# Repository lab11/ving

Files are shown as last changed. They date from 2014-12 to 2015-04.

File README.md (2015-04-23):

Rumblecation
=======

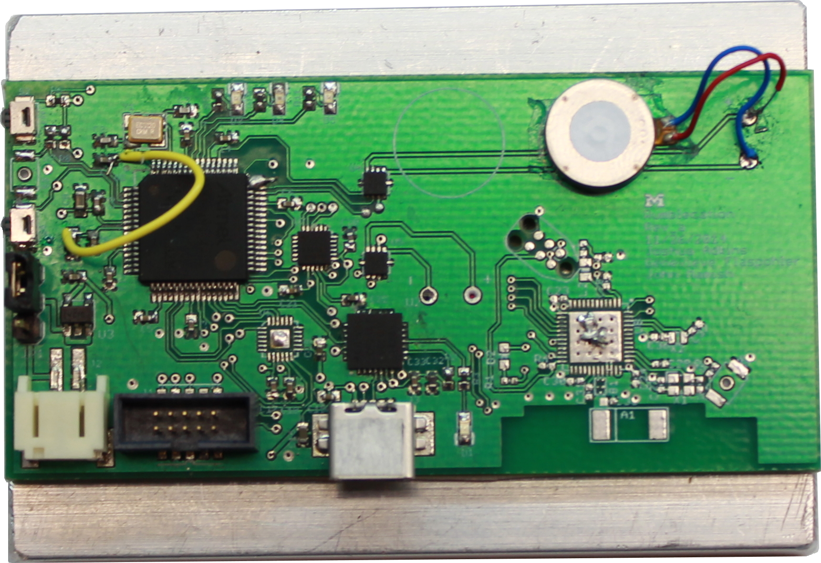
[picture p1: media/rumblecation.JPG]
Vibratory Communication Device


Mobile phones have vibratory motors which can transmit vibration, and 
accelerometers, which can sense vibration. Rumblecation takes advantage
of this hardware to communicate over vibration. Vibratory communication
would limit the communication domain to two or more physically coupled
devices, and this could be used to pair a specific subset of devices
sharing a surface such as table. 

Custom hardware was developed to closely emulate the hardware found in
common smartphones. A simple protocol was then designed for vibratory
communication and firmware was developed for our hardware to implement
this protocol.

Current work is focused on improving data rate and reliability, which
should be achievable by improving the algorithms that are processing 
accelerometer data.

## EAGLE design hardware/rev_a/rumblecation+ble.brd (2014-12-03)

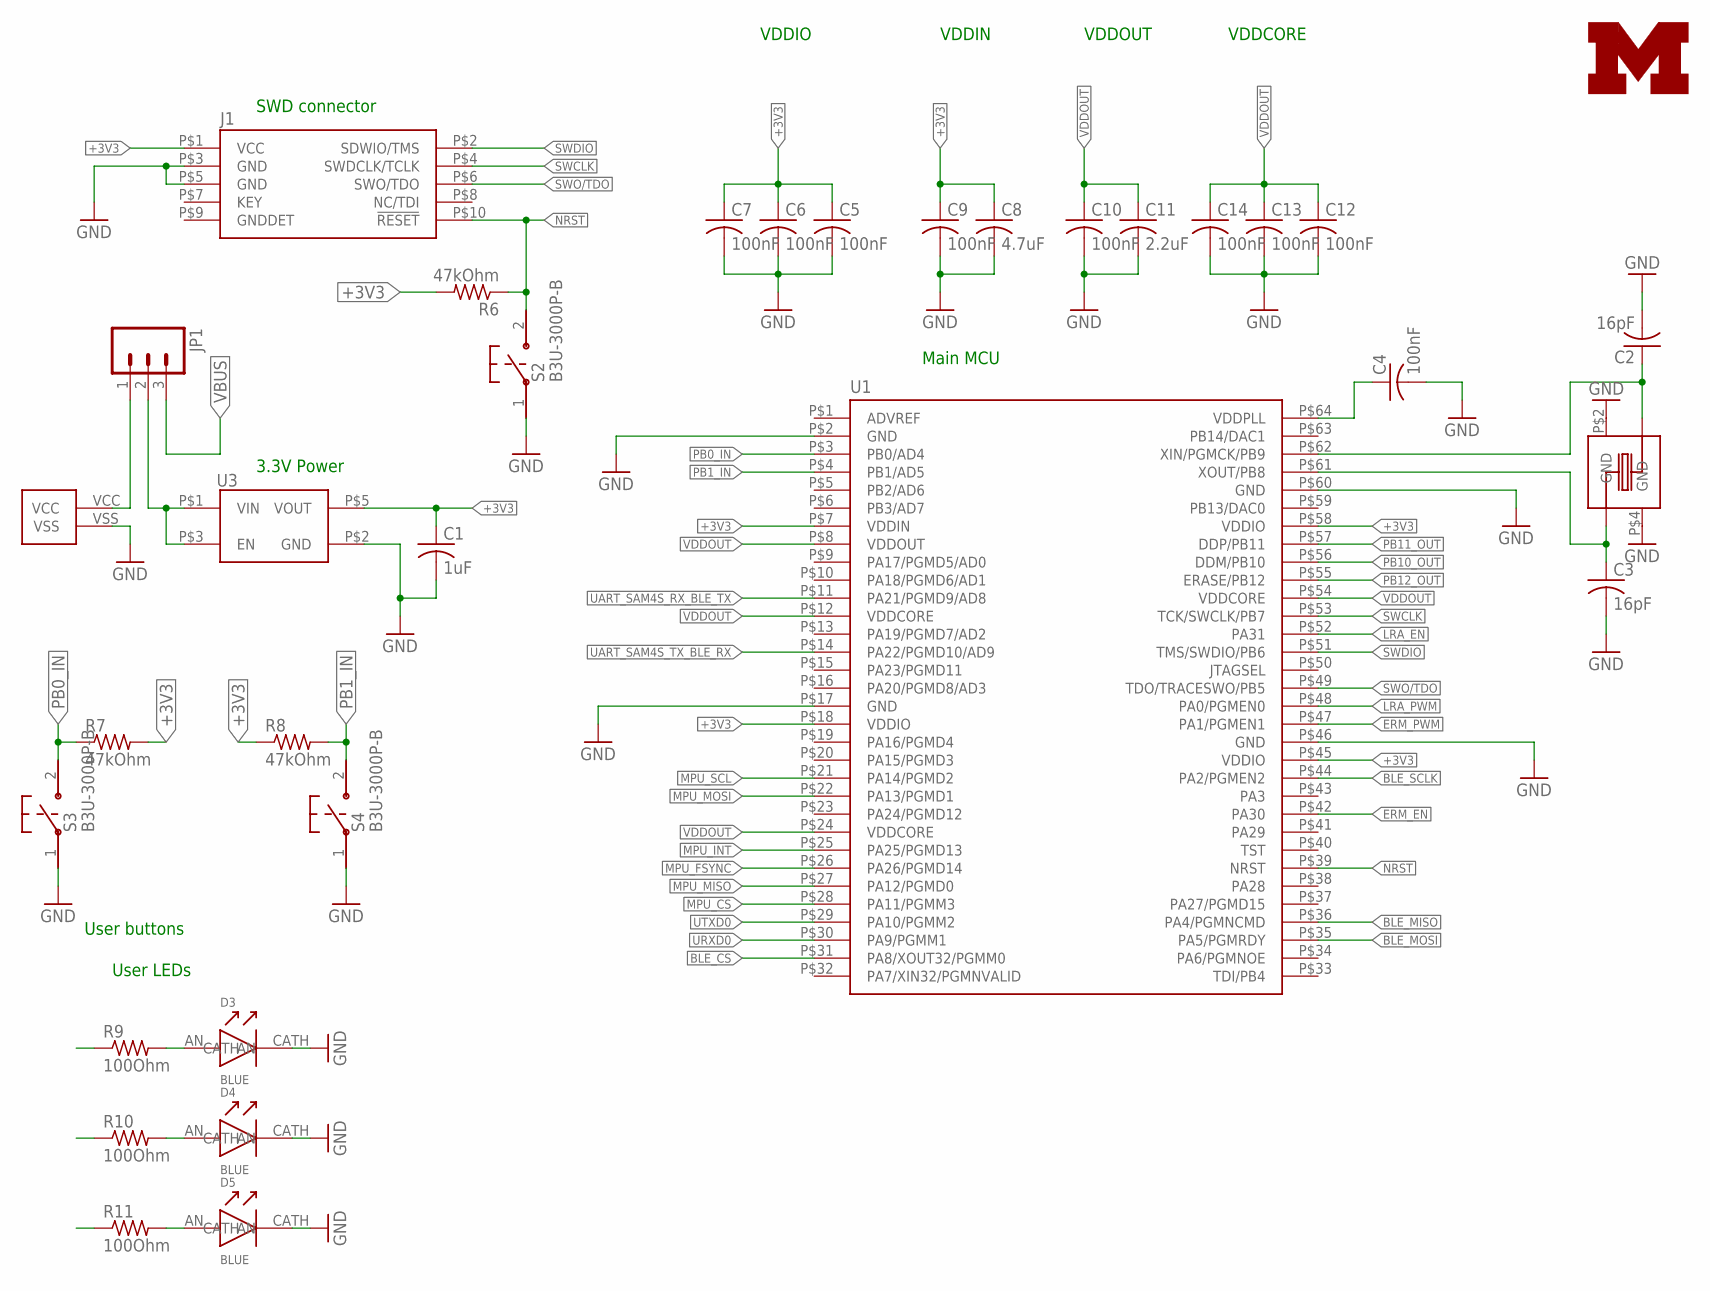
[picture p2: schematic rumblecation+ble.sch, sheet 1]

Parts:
C1: 1uF; C0402
C2, C3: 16pF; C0402
C4, C5, C6, C7, C9, C10, C12, C13, C14: 100nF; C0402
C8: 4.7uF; C0603
C11: 2.2uF; C0603
D3, D4, D5: BLUE; D0603
J1: FCI_CORTEX_SWD_CONNECTOR; FCI_10_PIN_SMD_0.5
J2: JST_S2B-PH-SM4-TB_CONNECTOR
JP1: M03PTH; 1X03
LOGO1: UMICH_SOLID_TINY; UMICH_SOLID_50MIL
R6, R7, R8: 47kOhm; R0402
R9, R10, R11: 100Ohm; R0402
S2, S3, S4: B3U-3000P-B
U1: ATSAM4S2BA-AU; ATMEL_10X10_QFP_64
U3: TLV73333PDBVT; TI_SOT-23-5
Y1: ECS_ECS-120-20-33-CKM-TR; ECS_ECX-32

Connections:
+3V3: C1.1, C5.1, C6.1, C7.1, C8.1, C9.1, J1.P$1 (VCC), R6.2, R7.2, R8.1, U1.P$7 (VDDIN), U1.P$18 (VDDIO), U1.P$45 (VDDIO), U1.P$58 (VDDIO), U3.P$5 (VOUT); also elsewhere on the board
BLE_CS: U1.P$31 (PA8/XOUT32/PGMM0); also elsewhere on the board
BLE_MISO: U1.P$36 (PA4/PGMNCMD); also elsewhere on the board
BLE_MOSI: U1.P$35 (PA5/PGMRDY); also elsewhere on the board
BLE_SCLK: U1.P$44 (PA2/PGMEN2); also elsewhere on the board
ERM_EN: U1.P$42 (PA30); also elsewhere on the board
ERM_PWM: U1.P$47 (PA1/PGMEN1); also elsewhere on the board
GND: C1.2, C2.2, C3.2, C4.2, C5.2, C6.2, C7.2, C8.2, C9.2, C10.2, C11.2, C12.2, C13.2, C14.2, D3.CATH, D4.CATH, D5.CATH, J1.P$3 (GND), J1.P$5 (GND), J2.VSS, S2.1, S3.1, S4.1, U1.P$2 (GND), U1.P$17 (GND), U1.P$46 (GND), U1.P$60 (GND), U3.P$2 (GND), Y1.P$2 (GND), Y1.P$4 (GND); also elsewhere on the board
LRA_EN: U1.P$52 (PA31); also elsewhere on the board
LRA_PWM: U1.P$48 (PA0/PGMEN0); also elsewhere on the board
MPU_CS: U1.P$28 (PA11/PGMM3); also elsewhere on the board
MPU_FSYNC: U1.P$26 (PA26/PGMD14); also elsewhere on the board
MPU_INT: U1.P$25 (PA25/PGMD13); also elsewhere on the board
MPU_MISO: U1.P$27 (PA12/PGMD0); also elsewhere on the board
MPU_MOSI: U1.P$22 (PA13/PGMD1); also elsewhere on the board
MPU_SCL: U1.P$21 (PA14/PGMD2); also elsewhere on the board
unnamed: JP1.2, U3.P$1 (VIN), U3.P$3 (EN)
unnamed: C4.1, U1.P$64 (VDDPLL)
unnamed: J2.VCC, JP1.1
unnamed: D3.AN, R9.2
unnamed: D4.AN, R10.2
unnamed: D5.AN, R11.2
NRST: J1.P$10 (!RESET!), R6.1, S2.2, U1.P$39 (NRST)
PB0_IN: R7.1, S3.2, U1.P$3 (PB0/AD4)
PB1_IN: R8.2, S4.2, U1.P$4 (PB1/AD5)
PB10_OUT: R10.1, U1.P$56 (DDM/PB10)
PB11_OUT: R9.1, U1.P$57 (DDP/PB11)
PB12_OUT: R11.1, U1.P$55 (ERASE/PB12)
SWCLK: J1.P$4 (SWDCLK/TCLK), U1.P$53 (TCK/SWCLK/PB7)
SWDIO: J1.P$2 (SDWIO/TMS), U1.P$51 (TMS/SWDIO/PB6)
SWO/TDO: J1.P$6 (SWO/TDO), U1.P$49 (TDO/TRACESWO/PB5)
UART_SAM4S_RX_BLE_TX: U1.P$11 (PA21/PGMD9/AD8); also elsewhere on the board
UART_SAM4S_TX_BLE_RX: U1.P$14 (PA22/PGMD10/AD9); also elsewhere on the board
URXD0: U1.P$30 (PA9/PGMM1); also elsewhere on the board
UTXD0: U1.P$29 (PA10/PGMM2); also elsewhere on the board
VBUS: JP1.3; also elsewhere on the board
VDDOUT: C10.1, C11.1, C12.1, C13.1, C14.1, U1.P$8 (VDDOUT), U1.P$12 (VDDCORE), U1.P$24 (VDDCORE), U1.P$54 (VDDCORE)
XIN: C2.1, U1.P$62 (XIN/PGMCK/PB9), Y1.P$1
XOUT: C3.1, U1.P$61 (XOUT/PB8), Y1.P$3

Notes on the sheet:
VDDIN
VDDOUT
VDDIO
VDDCORE
3.3V Power
SWD connector
Main MCU
User buttons
User LEDs

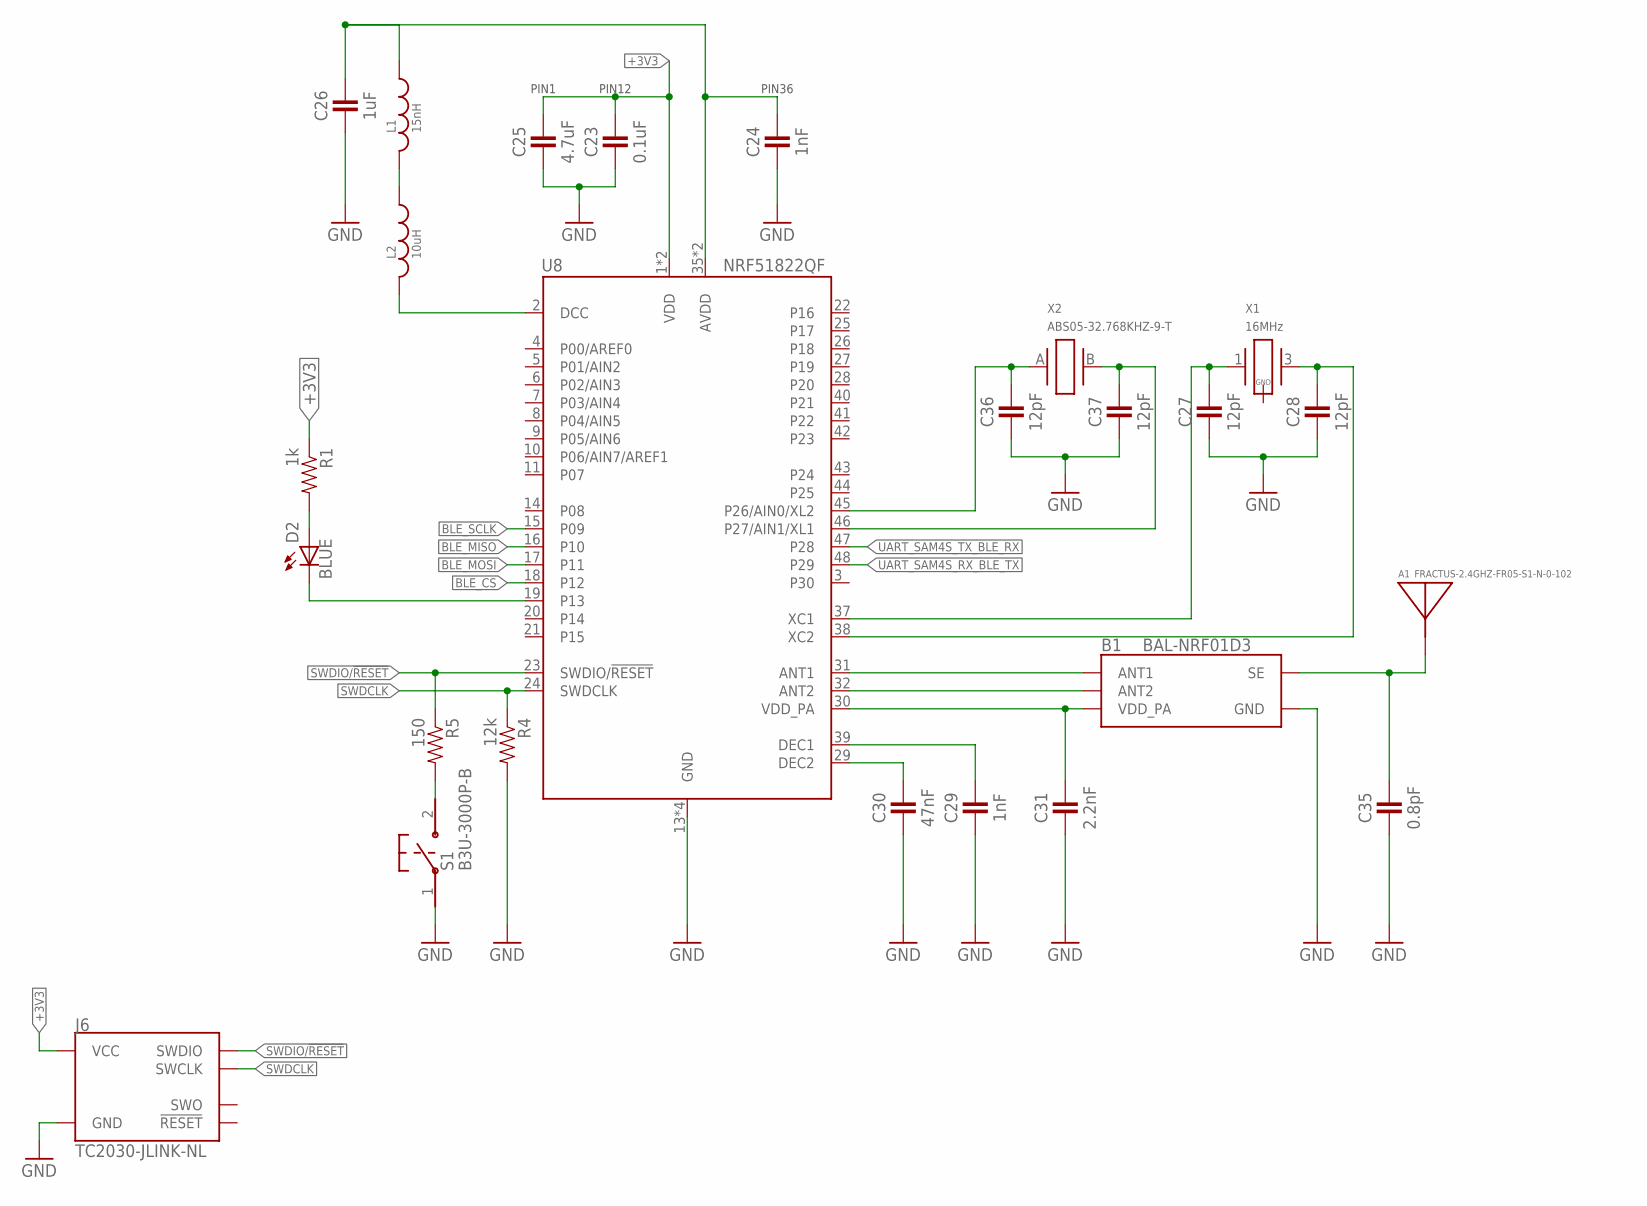
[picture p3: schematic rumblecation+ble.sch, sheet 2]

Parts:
A1: FRACTUS-2.4GHZ-FR05-S1-N-0-102; FRACTUS-ANTENNA-FR05-S1-N-0-102
B1: BAL-NRF01D3
C23: 0.1uF; 0402_CAP; DIGIKEY 445-4952-1-ND
C24, C29: 1nF; 0402_CAP; DIGIKEY 490-1303-1-ND
C25: 4.7uF; 0402_CAP; DIGIKEY 445-5947-1-ND
C26: 1uF; 0402_CAP; DIGIKEY 1276-1513-1-ND
C27, C28, C36, C37: 12pF; 0402_CAP; DIGIKEY 490-6197-1-ND
C30: 47nF; 0402_CAP; DIGIKEY 445-1264-1-ND
C31: 2.2nF; 0402_CAP; DIGIKEY 490-5419-1-ND
C35: 0.8pF; 0402_CAP; DIGIKEY 490-6269-1-ND
D2: BLUE; LED-0603
J6: TC2030-JLINK-NL; TC2030-IDC-NL
L1: 15nH; 0402_CAP; DIGIKEY 587-1521-1-ND
L2: 10uH; 0603_CAP; DIGIKEY 490-4025-1-ND
R1: 1k; 0402_RES; DIGIKEY RHM1.0KCECT-ND
R4: 12k; 0402_RES; DIGIKEY RHM12.0KCDCT-ND
R5: 150; 0402_RES; DIGIKEY RHM150CDCT-ND
S1: B3U-3000P-B
U8: NRF51822QF; QFN-48-6MM
X1: 16MHz; TXC-8Y; DIGIKEY 887-2003-1-ND
X2: ABS05-32.768KHZ-9-T; ABS05

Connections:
+3V3: C23.1, C25.1, J6.1 (VCC), R1.1, U8.1 (VDD), U8.12 (VDD); also elsewhere on the board
A0: C36.1, U8.45 (P26/AIN0/XL2), X2.A (1)
A1: C37.1, U8.46 (P27/AIN1/XL1), X2.B (2)
AVDD: C24.1, C26.1, L1.1, U8.35 (AVDD), U8.36 (AVDD)
BLE_CS: U8.18 (P12); also elsewhere on the board
BLE_MISO: U8.16 (P10); also elsewhere on the board
BLE_MOSI: U8.17 (P11); also elsewhere on the board
BLE_SCLK: U8.15 (P09); also elsewhere on the board
DCC: L2.2, U8.2 (DCC)
GND: B1.GND, C23.2, C24.2, C25.2, C26.2, C27.2, C28.2, C29.2, C30.2, C31.2, C35.2, C36.2, C37.2, J6.5 (GND), R4.2, S1.1, U8.13 (GND), U8.33 (GND), U8.34 (GND), U8.GND; also elsewhere on the board
unnamed: B1.ANT1, U8.31 (ANT1)
unnamed: B1.ANT2, U8.32 (ANT2)
unnamed: A1.1, B1.SE, C35.1
unnamed: L1.2, L2.1
unnamed: D2.C, U8.19 (P13)
unnamed: C27.1, U8.37 (XC1), X1.1
unnamed: C28.1, U8.38 (XC2), X1.3 (2)
unnamed: C29.1, U8.39 (DEC1)
unnamed: C30.1, U8.29 (DEC2)
unnamed: R5.2, S1.2
unnamed: D2.A, R1.2
SWDCLK: J6.4 (SWCLK), R4.1, U8.24 (SWDCLK)
SWDIO/!RESET: J6.2 (SWDIO), R5.1, U8.23 (SWDIO/!RESET)
UART_SAM4S_RX_BLE_TX: U8.48 (P29); also elsewhere on the board
UART_SAM4S_TX_BLE_RX: U8.47 (P28); also elsewhere on the board
VDD_PA: B1.VCC (VDD_PA), C31.1, U8.30 (VDD_PA)

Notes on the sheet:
PIN12
PIN1
PIN36

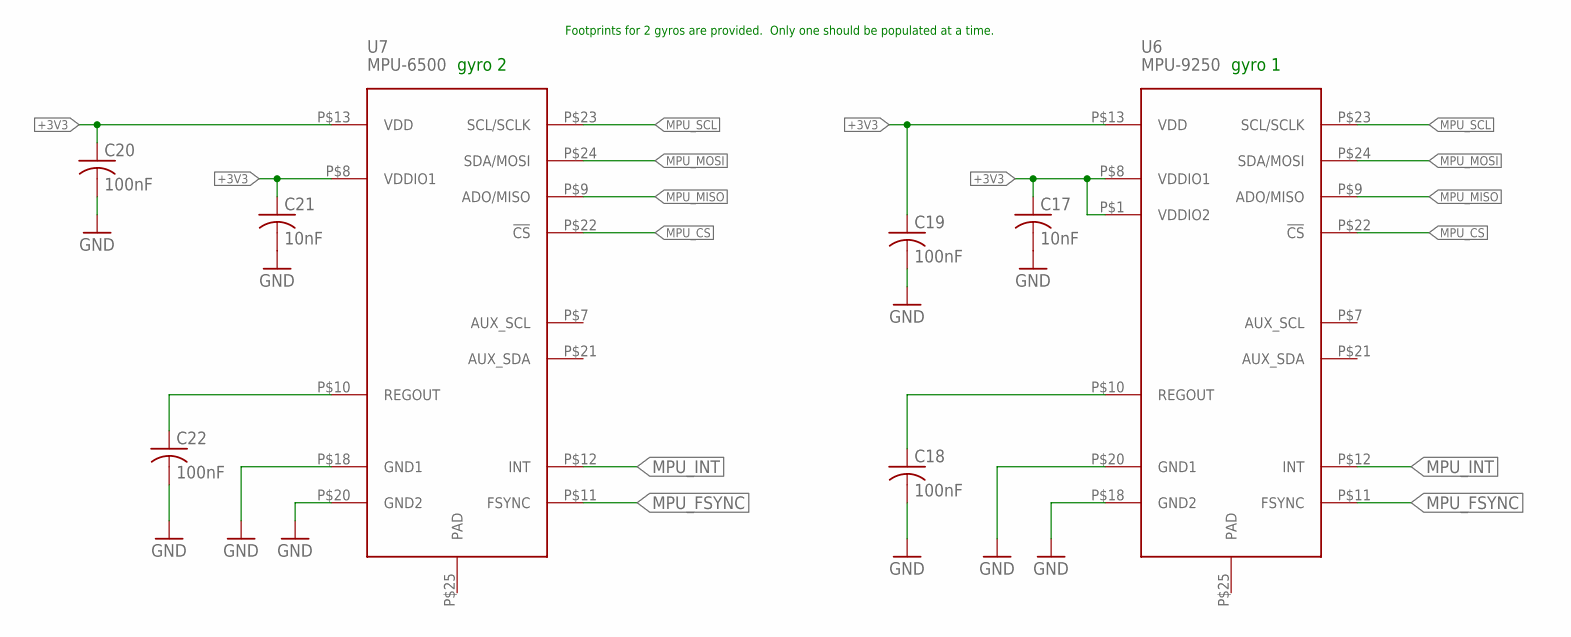
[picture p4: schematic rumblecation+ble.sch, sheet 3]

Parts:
C17, C21: 10nF; C0402
C18, C19, C20, C22: 100nF; C0402
U6: MPU-9250; MPU-9X50
U7: MPU-6500; MPU-9X50

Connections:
+3V3: C17.1, C19.1, C20.1, C21.1, C22.1, U6.P$1 (VDDIO2), U6.P$8 (VDDIO1), U6.P$13 (VDD), U7.P$8 (VDDIO1), U7.P$10 (REGOUT), U7.P$13 (VDD); also elsewhere on the board
GND: C17.2, C18.2, C19.2, C20.2, C21.2, C22.2, U6.P$18 (GND2), U6.P$20 (GND1), U7.P$18 (GND1), U7.P$20 (GND2); also elsewhere on the board
MPU_CS: U6.P$22 (!CS), U7.P$22 (!CS); also elsewhere on the board
MPU_FSYNC: U6.P$11 (FSYNC), U7.P$11 (FSYNC); also elsewhere on the board
MPU_INT: U6.P$12 (INT), U7.P$12 (INT); also elsewhere on the board
MPU_MISO: U6.P$9 (ADO/MISO), U7.P$9 (ADO/MISO); also elsewhere on the board
MPU_MOSI: U6.P$24 (SDA/MOSI), U7.P$24 (SDA/MOSI); also elsewhere on the board
MPU_SCL: U6.P$23 (SCL/SCLK), U7.P$23 (SCL/SCLK); also elsewhere on the board
unnamed: C18.1, U6.P$10 (REGOUT)

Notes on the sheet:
gyro 1
gyro 2
Footprints for 2 gyros are provided. Only one should be populated at a time.

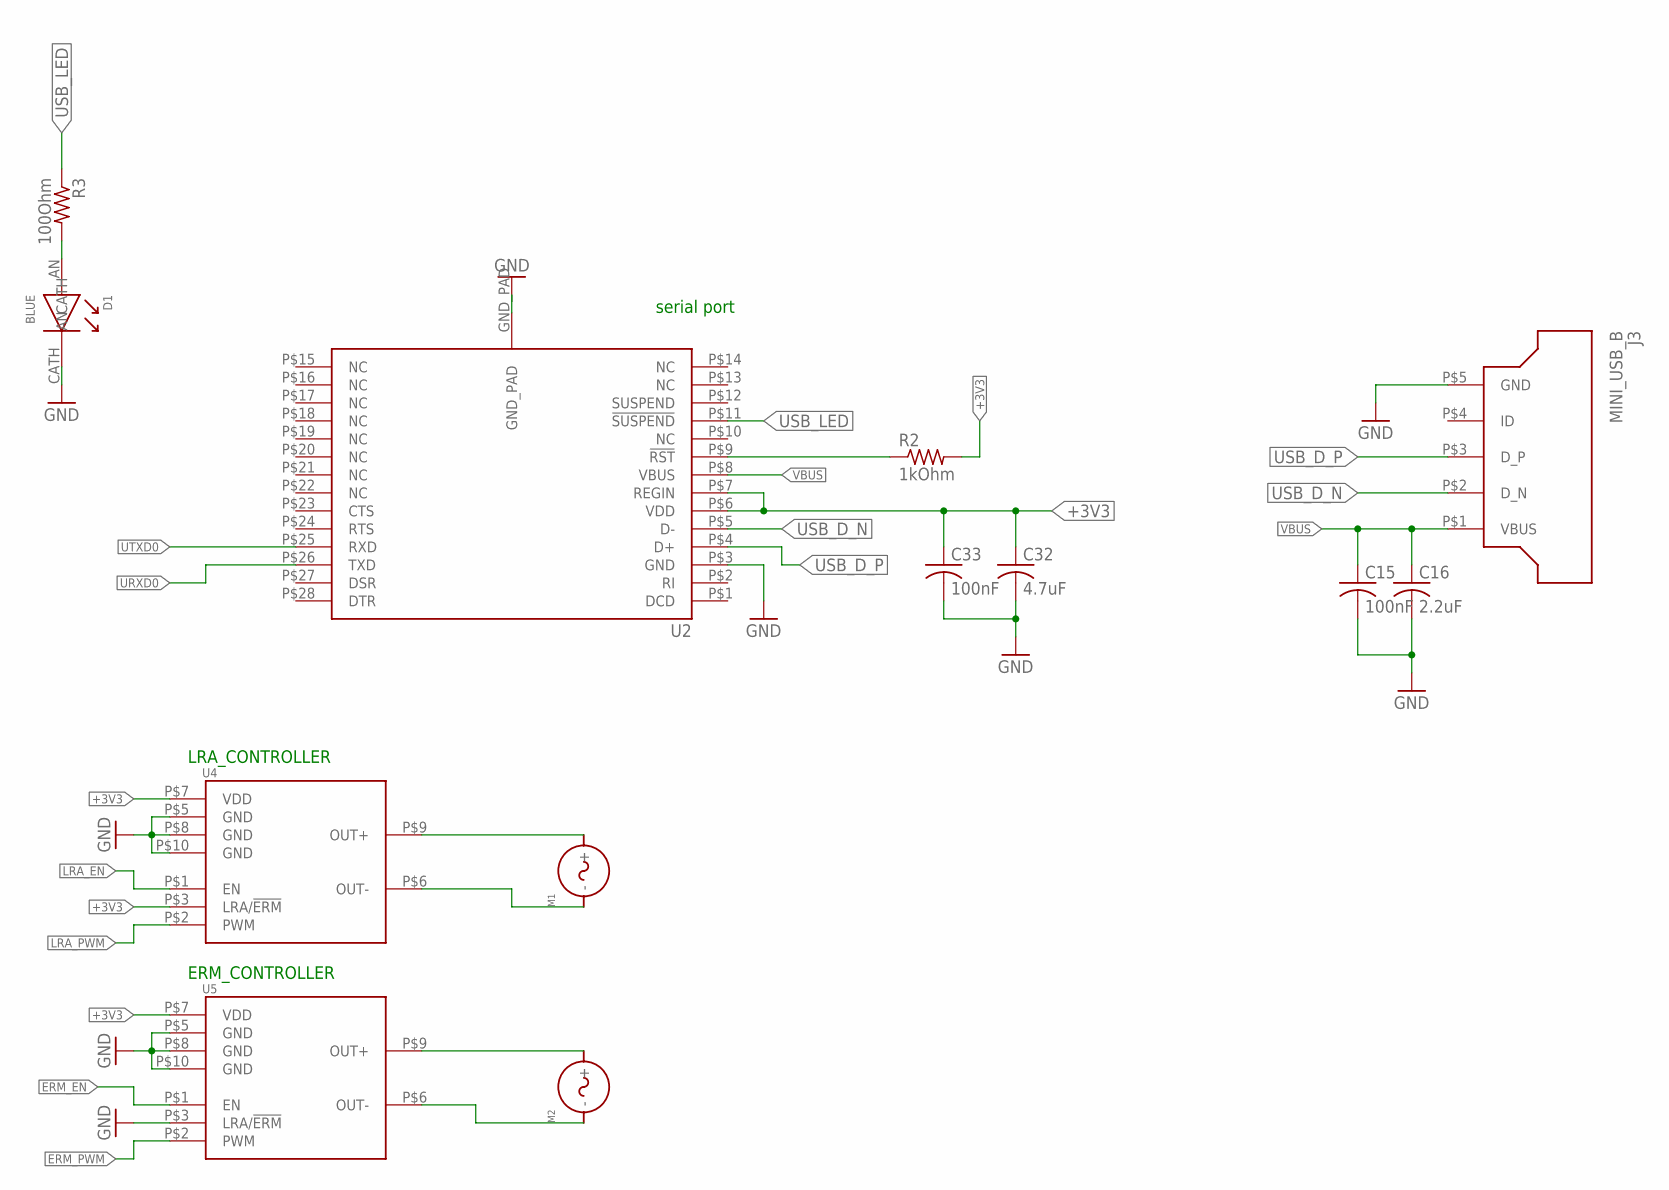
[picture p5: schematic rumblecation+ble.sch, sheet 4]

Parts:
C15, C33: 100nF; C0402
C16: 2.2uF; C0402
C32: 4.7uF; C0402
D1: BLUE; D0603
J3: MINI_USB_B; UX60SC-MB-5ST
M1: PRECISION_MICRODRIVES_C100-10; PRECISION_MICRODRIVES_10MM
M2: PRECISION_MICRODRIVES_310-113; PRECISION_MICRODRIVES_10MM
R2: 1kOhm; R0402
R3: 100Ohm; R0402
U2: SILABS_CP2102; SILABS_QFN28
U4, U5: TI_DRV2603; TI_S-PWQFN-N10

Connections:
+3V3: C32.1, C33.1, R2.2, U2.P$6 (VDD), U2.P$7 (REGIN), U4.P$3 (LRA/!ERM!), U4.P$7 (VDD), U5.P$7 (VDD); also elsewhere on the board
ERM_EN: U5.P$1 (EN); also elsewhere on the board
ERM_PWM: U5.P$2 (PWM); also elsewhere on the board
GND: C15.2, C16.2, C32.2, C33.2, D1.CATH, J3.P$5 (GND), U2.GND_PAD, U2.P$3 (GND), U4.P$5 (GND), U4.P$8 (GND), U4.P$10 (GND), U5.P$3 (LRA/!ERM!), U5.P$5 (GND), U5.P$8 (GND), U5.P$10 (GND); also elsewhere on the board
LRA_EN: U4.P$1 (EN); also elsewhere on the board
LRA_PWM: U4.P$2 (PWM); also elsewhere on the board
unnamed: R2.1, U2.P$9 (!RST!)
unnamed: M1.P$1 (-), U4.P$6 (OUT-)
unnamed: M1.P$2 (+), U4.P$9 (OUT+)
unnamed: D1.AN, R3.2
unnamed: M2.P$2 (+), U5.P$9 (OUT+)
unnamed: M2.P$1 (-), U5.P$6 (OUT-)
URXD0: U2.P$26 (TXD); also elsewhere on the board
USB_D_N: J3.P$2 (D_N), U2.P$5 (D-)
USB_D_P: J3.P$3 (D_P), U2.P$4 (D+)
USB_LED: R3.1, U2.P$11 (!SUSPEND!)
UTXD0: U2.P$25 (RXD); also elsewhere on the board
VBUS: C15.1, C16.1, J3.P$1 (VBUS), U2.P$8 (VBUS); also elsewhere on the board

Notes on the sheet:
LRA_CONTROLLER
ERM_CONTROLLER
serial port

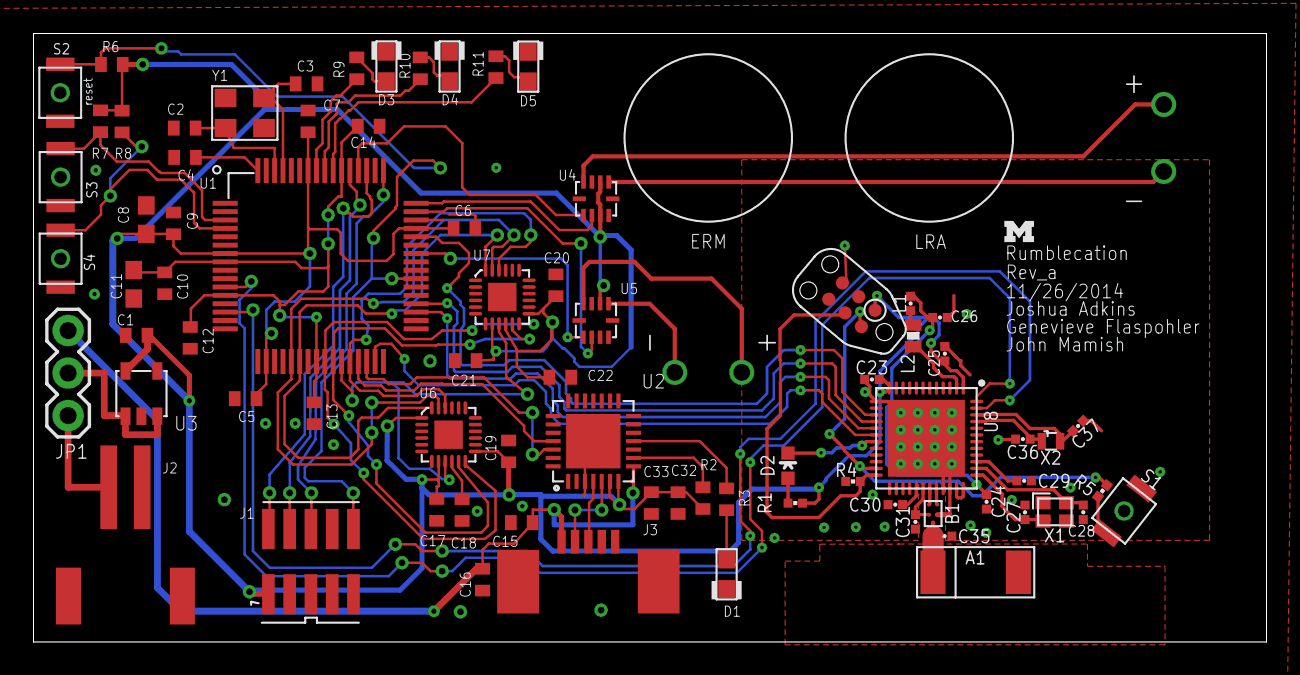
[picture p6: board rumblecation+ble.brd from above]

Board: 2 copper layers, 73.6 x 36.3 mm, 79 parts (0 on the bottom side), 67 nets.

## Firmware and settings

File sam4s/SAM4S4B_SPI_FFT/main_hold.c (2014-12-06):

/**
 * \file
 *
 * \brief Empty user application template
 *
 */

/*
 * Include header files for all drivers that have been imported from
 * Atmel Software Framework (ASF).
 */

#include <asf.h>
#include "spi.h"
#include "spi_master.h"
#include "arm_math.h"
#include "pio.h"
#include "tc.h"

#define CHANNEL0 0
#define CHANNEL1 1
#define READ_RES 16
#define SAMPLE_RATE_HZ 1000
#define PULSE_RATE_HZ 40
#define FFT_SIZE 64
#define FILTER_LOW 100
#define FILTER_HIGH 500
#define BIN_SIZE (SAMPLE_RATE_HZ/FFT_SIZE)

int HIGH_COUNTER = 0;
int HIGH_DIV = (SAMPLE_RATE_HZ/PULSE_RATE_HZ);
int SAMPLE_COUNTER= 0;

status_code_t status;
uint32_t SPIselect = 1;
int TOGGLE_S = 0;
int TOGGLE_M = 0;

#define ERROR_MESSAGE "INIT ERROR \r\n"
#define INIT_SUCCESS "INIT SUCCESS \r\n"
#define BREAKER "\r\n--------------------------------------\r\n"

// =============== UART1 =============== 
#define UART_SERIAL_BAUDRATE        57600
#define UART_SERIAL_CHANNEL_MODE	UART_MR_CHMODE_NORMAL
#define UART_SERIAL_MODE			UART_MR_PAR_NO


#define PINS_UART0          (PIO_PA9A_URXD0 | PIO_PA10A_UTXD0)
#define PINS_UART0_FLAGS    (PIO_PERIPH_A | PIO_DEFAULT)
#define PINS_UART0_MASK     (PIO_PA9A_URXD0 | PIO_PA10A_UTXD0)
#define PINS_UART0_PIO      PIOA
#define PINS_UART0_ID       ID_PIOA
#define PINS_UART0_TYPE     PIO_PERIPH_A
#define PINS_UART0_ATTR     PIO_DEFAULT

//=================SPI==================
#define SPI_BAUD 1000000
#define Z_LOW 64
#define Z_HIGH 63
#define PINS_SPI          (PIO_PA12A_MISO | PIO_PA13A_MOSI|PIO_PA11A_NPCS0 |PIO_PA14A_SPCK)
#define PINS_SPI_FLAGS    (PIO_PERIPH_A | PIO_DEFAULT)
#define PINS_SPI_MASK     (PIO_PA12A_MISO | PIO_PA13A_MOSI| PIO_PA11A_NPCS0 | PIO_PA14A_SPCK)
#define PINS_SPI_PIO      PIOA
#define PINS_SPI_ID       ID_PIOA
#define PINS_SPI_TYPE     PIO_PERIPH_A
#define PINS_SPI_ATTR     PIO_DEFAULT
struct spi_device CHANNEL_0 = {.id = 0};
char buffer[255];
char print_buf[255];
uint8_t rx_data[2];

//=================Function Definitions================
void writeRegister(uint8_t reg, uint8_t val);
status_code_t readRegister(uint8_t reg, uint8_t* val, int bytesToRead);
void spi_init(void);
void console_write(char* input, int len);
void shiftLeft(void);
void copyArray(void);
void toggle(uint32_t LED_INPUT);
void toggle_motor(uint32_t MOTOR_INPUT);
void pwm_init_start(void);
void on_off_key(void);
void tc_config(uint32_t freq_desired, Tc* TCn, uint32_t CHANNEL, uint32_t PER_ID);

//=================PWM============================
//PWM, pa0 LRA, pa1 ERM PWM
#define ERM_on_off PIO_PA30
#define LRA_on_off PIO_PA31

pwm_channel_t g_pwm_channel_led;

#define PINS_PWM0          (PIO_PA0A_PWMH0)
#define PINS_PWM0_FLAGS    (PIO_PERIPH_A | PIO_DEFAULT)
#define PINS_PWM0_MASK     (PIO_PA0A_PWMH0)
#define PINS_PWM0_PIO      PIOA
#define PINS_PWM0_ID       ID_PIOA
#define PINS_PWM0_TYPE     PIO_PERIPH_A
#define PINS_PWM0_ATTR     PIO_DEFAULT

/** PWM frequency in Hz */
#define PWM_FREQUENCY      50000
/** Period value of PWM output waveform */
#define PERIOD_VALUE      100
/** Initial duty cycle value */
#define INIT_DUTY_VALUE    30 //40 is off, 30, is slightly on, 0 is full on

//=================FFT Globals================
q31_t samples_fix[FFT_SIZE*2];
q31_t samples_hold[FFT_SIZE*2];
q31_t magnitudes_fix[FFT_SIZE];
q31_t max_finder[FFT_SIZE];

q31_t holder[1000];

volatile uint8_t high = 0;
volatile uint8_t low = 0;
q31_t val = 0;
q31_t max_val = 0;
uint32_t max_index = 0;
volatile int dom_freq_h = 0;
volatile int dom_freq_l = 0;
const arm_cfft_radix4_instance_q31 fft_inst_fix;
volatile int hasSampled = false;
volatile int isDone = false;
int sampleCounter = 0;


//Interrupt service routine called by timer interrupt at frequency SAMPLE_RATE_HZ
void TC0_Handler(void)
{
	if(tc_get_status(TC0,CHANNEL0)){
		if (sampleCounter > 1) {
			//NVIC_ClearPendingIRQ(TC0_IRQn);
			sampleCounter = 0;
		}//End if
		else {
			//NVIC_ClearPendingIRQ(TC0_IRQn);

			readRegister(Z_HIGH, &rx_data, 2);
			val = (q31_t)((rx_data[0]<<8)+rx_data[1]); //high << 8 + low
			val = (val << 30-READ_RES);

			shiftLeft();
			samples_fix[FFT_SIZE*2-2] = val;
			samples_fix[FFT_SIZE*2-1] = (q31_t)0;
			copyArray();
			toggle(PIO_PB11);
			sampleCounter +=2;
		}//End else
	}//End if Channel 1
	
	HIGH_COUNTER++;

	if(HIGH_COUNTER > HIGH_DIV) {
		HIGH_COUNTER = 0;
		pio_set(PIOB, PIO_PB12);		
		on_off_key();
	}
	NVIC_ClearPendingIRQ(TC0_IRQn);

}//End handler

//  void PWM_Handler(void)
//  {
// 	static uint32_t ul_count = 0;  /* PWM counter value */
// 	static uint32_t ul_duty = INIT_DUTY_VALUE;  /* PWM duty cycle rate */
// 	static uint8_t fade_in = 1;  /* LED fade in flag */
// 	uint32_t events = pwm_channel_get_interrupt_status(PWM);
// 
// 	/* Interrupt on PIN_PWM_LED0_CHANNEL */
// 	if ((events & (1 << PWM_CHANNEL_0)) == (1 << PWM_CHANNEL_0)) {
// 		ul_count++;
// 
// 		/* Fade in/out */
// 		if (ul_count == (PWM_FREQUENCY / (PERIOD_VALUE - INIT_DUTY_VALUE))) {
// 			/* Fade in */
// 			if (fade_in) {
// 				ul_duty++;
// 				if (ul_duty == PERIOD_VALUE) {
// 					fade_in = 0;
// 				}
// 			} else {
// 				/* Fade out */
// 				ul_duty--;
// 				if (ul_duty == INIT_DUTY_VALUE) {
// 					fade_in = 1;
// 				}
// 			}
// 
// 			/* Set new duty cycle */
// 			ul_count = 0;
// 			g_pwm_channel_led.channel = PWM_CHANNEL_0;
// 			pwm_channel_update_duty(PWM, &g_pwm_channel_led, ul_duty);
// 			g_pwm_channel_led.channel = PWM_CHANNEL_0;
// 			pwm_channel_update_duty(PWM, &g_pwm_channel_led, ul_duty);
// 		}
// 	}
//  }


int main (void)
{
	sysclk_init();
	board_init();
	
	// set the pins to use the uart peripheral
	pmc_enable_periph_clk(ID_UART0);
	pmc_enable_periph_clk(ID_PIOA);

	pio_configure(PINS_UART0_PIO, PINS_UART0_TYPE, PINS_UART0_MASK, PINS_UART0_ATTR);
	pio_configure(PINS_PWM0_PIO, PINS_PWM0_TYPE, PINS_PWM0_MASK, PINS_PWM0_ATTR);

	//enable the uart peripherial clock
	pmc_enable_periph_clk(ID_UART0);
	pmc_enable_periph_clk(PIOB); 

	const sam_uart_opt_t uart1_settings =
	{ sysclk_get_cpu_hz(), UART_SERIAL_BAUDRATE, UART_SERIAL_MODE };

	uart_init(UART0,&uart1_settings);      //Init UART1 and enable Rx and Tx
	 
	spi_init();
	
	//Initialize FFT Sampling
 	int status = 1;
	status = arm_cfft_radix4_init_q31(&fft_inst_fix, FFT_SIZE, 0, 1); //Selects forward transform and bit reversal of output
 	if (status == ARM_MATH_ARGUMENT_ERROR){
		console_write(ERROR_MESSAGE, sizeof(ERROR_MESSAGE));
 	}
	 else if(status == ARM_MATH_SUCCESS) {
		console_write(INIT_SUCCESS, sizeof(INIT_SUCCESS));
	 }
	
	MATRIX->CCFG_SYSIO |= CCFG_SYSIO_SYSIO10;
	MATRIX->CCFG_SYSIO |= CCFG_SYSIO_SYSIO11;
	MATRIX->CCFG_SYSIO |= CCFG_SYSIO_SYSIO12;
	
	//Disable watch dog
	WDT->WDT_MR |= WDT_MR_WDDIS; 
	
	//gpio_configure_pin(PIO_PB10_IDX, PIO_PERIPH_B|PIO_DEFAULT);
	pio_set_output(PIOB, PIO_PB10, HIGH, DISABLE, ENABLE);
	pio_set_output(PIOB, PIO_PB11, HIGH, DISABLE, ENABLE);
	pio_set_output(PIOB, PIO_PB12, HIGH, DISABLE, ENABLE);
	pio_set_output(PIOA, PIO_PA30, LOW, DISABLE, ENABLE);
	pio_set_output(PIOA, PIO_PA31, LOW, DISABLE, ENABLE);
	pio_set_input(PIOB, PIO_PB1, PIO_PULLUP);
	
	//Initizlize PMC
	pwm_init_start();
	
	//Initialzie Timer Interrupt
	tc_config(SAMPLE_RATE_HZ, TC0, CHANNEL0, ID_TC0);
	//tc_config(PULSE_RATE_HZ, TC0, CHANNEL1, ID_TC0);
	
	NVIC_DisableIRQ(TC0_IRQn);
	NVIC_ClearPendingIRQ(TC0_IRQn);
	NVIC_SetPriority(TC0_IRQn,0);
 	NVIC_EnableIRQ(TC0_IRQn);
	 
	while(1) {
		gpio_set_pin_high(PIO_PB10_IDX);

		
		if(pio_get(PIOB, PIO_INPUT | PIO_PERIPH_B, PIO_PB1)) {
			toggle_motor(LRA_on_off);
			toggle(PIO_PB10);
		}
		
		 if(sampleCounter < 1) { //If no new sample, just print debug statement
			sprintf(print_buf, "Sample_c: %d \r\n", sampleCounter);
			//console_write(print_buf, sizeof(print_buf));
		 }
		 else{
			 //Disable timer interrupt so that the FFT can complete before being interrupted
			 NVIC_DisableIRQ(TC0_IRQn);
			 
			 //Perform the FFT transform
			 arm_cfft_radix4_q31(&fft_inst_fix, samples_hold);
			 
			 // Calculate magnitude of complex numbers outq31put by the FFT.
 			arm_cmplx_mag_q31(samples_hold, magnitudes_fix, FFT_SIZE);
			
			//Copies magnitudes over to new array for finding max; only copy first half becuase the 
			//complex forier transform has even symmetry so only the first half of the data is relevent
			for (int i = 0; i < FFT_SIZE/2; ++i) {
			  max_finder[i] = magnitudes_fix[i];
			}
			
			//Uncomment to display the DC mangitude component of the signal
			//sprintf(print_buf, "magnitudes[0] \t %d \r\n", magnitudes_fix[0]);
			//console_write(print_buf, sizeof(print_buf));
			
			//Set the DC component of the magnitudes to zero; it tends to be larger than the other
			//frequency compenents, so it scews the max frequency finder
			
			/*for (int i = 0; i < (FILTER_LOW/BIN_SIZE); i++)
			{
				max_finder[i] = 0;
			}
			for (int i = FILTER_HIGH/BIN_SIZE; i < FFT_SIZE; i++){
				max_finder[i] = 0;
			}*/
			max_finder[0] = 0;
			
			//Find the magnitude of the dominent frequency
			//arm_max_q31(max_finder, FFT_SIZE, &max_val, &max_index);
			
			/*for(int i = 0; i < FFT_SIZE; i++) {
				sprintf(buffer, "%d - %d: %d", (SAMPLE_RATE_HZ/FFT_SIZE)*i, (SAMPLE_RATE_HZ/FFT_SIZE)*i+(SAMPLE_RATE_HZ/FFT_SIZE), magnitudes_fix[i]);
				console_write(buffer, sizeof(print_buf));
			}*/
	
			//Calulate the upper and lower range of the dominent frequency 
			dom_freq_l = BIN_SIZE*max_index;
			dom_freq_h = dom_freq_l + BIN_SIZE;
			
			//Re-enable the Timer interrupt
			NVIC_EnableIRQ(TC0_IRQn);
			
			/*for(int i = 0; i < FFT_SIZE; i++) {
				sprintf(buffer, "%d - %d\t", (SAMPLE_RATE_HZ/FFT_SIZE)*i, (SAMPLE_RATE_HZ/FFT_SIZE)*i+(SAMPLE_RATE_HZ/FFT_SIZE));
				console_write(buffer, sizeof(print_buf));
				console_write("\r\n", 2);
			}*/
			for(int i = 0; i < FFT_SIZE/2; i++) {
				sprintf(buffer, "%d, ", max_finder[i]);
				console_write(buffer, sizeof(print_buf));
			}
			console_write(BREAKER, sizeof(BREAKER));
			
			//Print the dominent frequency range
			//sprintf(print_buf, "%d - %d  @ %d Val: %d \r\n", dom_freq_l, dom_freq_h, max_index, max_val);
			//console_write(print_buf, sizeof(print_buf));
			
			//Uncomment to output accelerometer data
			//sprintf(buffer, "Z_HIGH: %x\tZ_LOW: %x\tZ_VAL: %d \r\n", rx_data[0], rx_data[1], total);
			//console_write(buffer, sizeof(buffer));
		}//End if has sampled
	}//End while
}//End main

void console_write(char* input, int len){
	for(int i = 0; i < len; i++) {
		while(!uart_is_tx_buf_empty(UART0));
		uart_write(UART0, input[i]);
	}
	return;
}

void spi_init(void) {
	//Initialize SPI
	pmc_enable_periph_clk(ID_SPI);
	pio_configure(PINS_SPI_PIO, PINS_SPI_TYPE, PINS_SPI_MASK, PINS_SPI_ATTR);

	//Choose appropriate SPI_MODE_n
	// 	Mode CPOL NCPHA SHIFTEDGE CAPTUREEDGE INACTIVELEVEL
	// 	0 0 1 Falling Rising Low
	// 	1 0 0 Rising Falling Low
	// 	2 1 1 Rising Falling High
	// 	3 1 0 Falling Rising High

	spi_master_init(SPI);
	spi_master_setup_device(SPI, &CHANNEL_0, SPI_MODE_3, SPI_BAUD, SPIselect); //mySPIselect is not used
	spi_enable(SPI);

	writeRegister(26, 0x00); //Config reg
	writeRegister(28, 0x00); //Accel config
	writeRegister(29, 0x08); //Config2
	writeRegister(35, 0x00); //FIFO enable 0x08
	writeRegister(106, 0x50); //User control 0101 0000
	writeRegister(107, 0x00);//Power managment 0000 0000
	//writeRegister(108, 0x1F); //Disable all axis and gryo except ACC_X 0001 1111
	writeRegister(108, 0x00); //Enable all axis and gryo
}

void writeRegister(uint8_t reg, uint8_t val) {
	//uint8_t data_Tx = reg;
	spi_select_device(SPI, &CHANNEL_0);
	uint8_t data_Tx[2] = {reg, val};
	spi_write_packet(SPI, data_Tx, 2);
	//spi_write_single(SPI, reg);
	//spi_write_single(SPI, val);
	spi_deselect_device(SPI, &CHANNEL_0);
	return status;
}

status_code_t readRegister(uint8_t reg, uint8_t* val, int bytesToRead){
	uint8_t inByte = 0;
	uint8_t REG_ADDR_R = reg | 0x80;

	spi_select_device(SPI, &CHANNEL_0);
	//spi_write_single(SPI, REG_ADDR_R);
	status = spi_read_packet(SPI, val, bytesToRead);
	spi_deselect_device(SPI, &CHANNEL_0);
	return status;
}


// Configuration function for the Timer.
void tc_config(uint32_t freq_desired, Tc* TCn, uint32_t CHANNEL, uint32_t PER_ID)
{
	// INPUTS:
	//	freq_desired	The desired rate at which to call the ISR, Hz.
	
	uint32_t ul_div;
	uint32_t ul_tcclks;
	uint32_t ul_sysclk = sysclk_get_cpu_hz();
	uint32_t counts;	
	
	// Configure PMC				
	pmc_enable_periph_clk(PER_ID);

	// Configure TC for a 4Hz frequency and trigger on RC compare.
	tc_find_mck_divisor(
		(uint32_t)freq_desired,	// The desired frequency as a uint32. 
		ul_sysclk,				// Master clock freq in Hz.
		&ul_div,				// Pointer to register where divisor will be stored.
		&ul_tcclks,				// Pointer to reg where clock selection number is stored.
		ul_sysclk);				// Board clock freq in Hz.
	tc_init(TCn, CHANNEL, ul_tcclks | TC_CMR_CPCTRG);
	
	// Find the best estimate of counts, then write it to TC register C.
	counts = (ul_sysclk/ul_div)/freq_desired;	
	tc_write_rc(TCn, 0, counts);						

	// Enable interrupts for this TC, and start the TC.		
	tc_enable_interrupt(TCn, CHANNEL,TC_IER_CPCS);				// Enable interrupt.
	tc_start(TCn,CHANNEL);										// Start the TC.

}

void shiftLeft(void) {
  for(int i = 0; i < FFT_SIZE*2; i++)
  {
    samples_fix[i] = samples_fix[i+2];
  }
}

void copyArray(void) {
  for(int i = 0; i < FFT_SIZE*2; i++) {
    samples_hold[i] = samples_fix[i];
  }
}

void toggle(uint32_t LED_INPUT){
	if(TOGGLE_S){
		pio_set(PIOB, LED_INPUT);
		TOGGLE_S = 0;
	}
	else{
		pio_clear(PIOB, LED_INPUT);
		TOGGLE_S = 1;
	}//End else
	
}

void toggle_motor(uint32_t MOTOR_INPUT){
	if(TOGGLE_M){
		pio_set(PIOA, MOTOR_INPUT);
		TOGGLE_M = 0;
	}
	else{
		pio_clear(PIOA, MOTOR_INPUT);
		TOGGLE_M = 1;
	}//End else
	

}

void pwm_init_start(void) {
	//pio_set(PIOA, PIO_PA30);//ERM
	pio_set(PIOA, PIO_PA31);//LRA
		//Enable PIO
	pmc_enable_periph_clk(PIOA);
	pmc_enable_periph_clk(ID_PWM);
	
	pwm_channel_disable(PWM, PWM_CHANNEL_0);

	
	pwm_clock_t clock_setting = {
	.ul_clka = PWM_FREQUENCY * PERIOD_VALUE,
	.ul_clkb = 0,
	.ul_mck = sysclk_get_cpu_hz()
	};
	pwm_init(PWM, &clock_setting);
	
	
	/* Initialize PWM channel for LED0 */
	/* Period is left-aligned */
	g_pwm_channel_led.alignment = PWM_ALIGN_LEFT;
	/* Output waveform starts at a low level */
	g_pwm_channel_led.polarity = PWM_LOW;
	/* Use PWM clock A as source clock */
	g_pwm_channel_led.ul_prescaler = PWM_CMR_CPRE_CLKA;
	/* Period value of output waveform */
	g_pwm_channel_led.ul_period = PERIOD_VALUE;
	/* Duty cycle value of output waveform */
	g_pwm_channel_led.ul_duty = INIT_DUTY_VALUE;
	g_pwm_channel_led.channel = PWM_CHANNEL_0;
	pwm_channel_init(PWM, &g_pwm_channel_led);
	
	NVIC_DisableIRQ(PWM_IRQn);
	NVIC_ClearPendingIRQ(PWM_IRQn);
	NVIC_SetPriority(PWM_IRQn, 0);
	NVIC_EnableIRQ(PWM_IRQn);

	/* Enable channel counter event interrupt */
	pwm_channel_disable_interrupt(PWM, PWM_CHANNEL_0, 0);
	//pwm_channel_enable_interrupt(PWM, PWM_CHANNEL_0, 0);
	pwm_channel_enable(PWM, PWM_CHANNEL_0);
	
}

void on_off_key(void){
	uint32_t ul_duty;
	if(TOGGLE_M){
		ul_duty = 20;
		TOGGLE_M = 0;
	}
	else{
		ul_duty = 50;
		TOGGLE_M = 1;
	}//End else
	
	g_pwm_channel_led.channel = PWM_CHANNEL_0;
	pwm_channel_update_duty(PWM, &g_pwm_channel_led, ul_duty);
	
}

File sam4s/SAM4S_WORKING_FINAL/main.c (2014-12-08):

#include <asf.h>
#include "rumblecation.h"
#include "rumbleTxRx.h"

#define UART_SERIAL_BAUDRATE        57600
#define UART_SERIAL_CHANNEL_MODE	UART_MR_CHMODE_NORMAL
#define UART_SERIAL_MODE			UART_MR_PAR_NO


#define PINS_UART0          (PIO_PA9A_URXD0 | PIO_PA10A_UTXD0)
#define PINS_UART0_FLAGS    (PIO_PERIPH_A | PIO_DEFAULT)
#define PINS_UART0_MASK     (PIO_PA9A_URXD0 | PIO_PA10A_UTXD0)
#define PINS_UART0_PIO      PIOA
#define PINS_UART0_ID       ID_PIOA
#define PINS_UART0_TYPE     PIO_PERIPH_A
#define PINS_UART0_ATTR     PIO_DEFAULT


void initLeds(void);
void uartInit(void);
void callback(uint8_t);
void spi_init(void);

uint8_t transmitBuf[256];
uint8_t transmitBufRead = 0;
uint8_t transmitBufWrite = 0;
char buffer[255];
int indexer = 0;


int main (void)
{
	sysclk_init();
	wdt_disable(WDT);
	initLeds();
	rumblecationInit();
	uartInit();
	
	volatile int i;
	delay_ms(3000);
	indexer = sprintf(buffer, "Starting \r\n");
	console_write(buffer, indexer);
	
	
	rumbleListen(callback);
	while(1) {

		//uart_write(UART0, 's');
		//i++;
		/*if(transmitBufRead != transmitBufWrite) {
			uart_write(UART0, transmitBuf[transmitBufRead]);
			transmitBufRead++;
		}*/
		
		if(uart_is_rx_ready(UART0)) {
			uint8_t in;
			uart_read(UART0, &in);
			uart_write(UART0, in);
			rumbleStop();
			rumbleSend(in);
			delay_ms(600);
			rumbleListen(callback);
		}
		
	}

}




void callback(uint8_t character){
	indexer = sprintf(buffer, "%c", character);
	console_write(buffer, indexer);
}

void initLeds(void) {
	MATRIX->CCFG_SYSIO |= CCFG_SYSIO_SYSIO12;
	MATRIX->CCFG_SYSIO |= CCFG_SYSIO_SYSIO11;
	MATRIX->CCFG_SYSIO |= CCFG_SYSIO_SYSIO10;
	
	pmc_enable_periph_clk(ID_PIOB);
	pmc_enable_periph_clk(ID_PIOA);
	pio_set_output(PIOB, PIO_PB10, LOW, DISABLE, ENABLE);
	pio_set_output(PIOB, PIO_PB11, LOW, DISABLE, ENABLE);
	pio_set_output(PIOB, PIO_PB12, LOW, DISABLE, ENABLE);
}

void uartInit() {
	
	pio_configure(PINS_UART0_PIO, PINS_UART0_TYPE, PINS_UART0_MASK, PINS_UART0_ATTR);
	
	pmc_enable_periph_clk(ID_UART0);

	const sam_uart_opt_t uart1_settings =
	{ 120000000, UART_SERIAL_BAUDRATE, UART_SERIAL_MODE };

	uart_init(UART0,&uart1_settings);
	uart_enable_interrupt(UART0,UART_IER_RXRDY);
	uart_enable_rx(UART0);
}

/*void UART0_Handler(void) {
	uint8_t in;
	uart_read(UART0,&in);
	transmitBuf[transmitBufWrite] = in;
	transmitBufWrite++;
}*/

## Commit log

2014-11-14 Arduino MPU driver
2014-11-21 Made new I2c Sketch
2014-11-21 fixed I2c test file
    [I2Ctest.ino]
2014-11-21 fixed i2c test compiler error
    [I2Ctest.ino]
2014-11-21 Python FFT Visulizer added and python scripts
    [teensy_fft_hardware.fzz]
2014-11-25 Added rumblcation+ ble board and schematic
    [rumblecation+ble.brd, rumblecation+ble.sch]
2014-11-26 Added newest board, schematic and lib files. Updated visualization file
    [rumblecation+ble.brd, rumblecation+ble.sch]
2014-11-26 Fixed directory organization
    [rumblecation+ble.brd, rumblecation+ble.sch, teensy_fft_hardware.fzz]
2014-11-26 Fixed SPI bus
2014-11-26 fixed silab usb-uart, added fsync and int to accell, updated schematic prettiness, fixed regout on accel
    [rumblecation+ble.brd, rumblecation+ble.sch]
2014-11-26 Added a power selector header, fixed some routing errors
    [rumblecation+ble.brd, rumblecation+ble.sch]
2014-11-26 Final board revision - being sent for production
    [rumblecation+ble.brd, rumblecation+ble.sch]
2014-12-04 FFT + timable interrupts, functional
2014-12-04 added mangitude and max frequency peak finding at 1000Hz
2014-12-04 added shift left functionality and performed FFT with every new sample, as opposed to the previous code that only ran the FFT when the buffer filled with the ful FFT_SIZE*2 samples
2014-12-05 FFT and SPI for SAM4S4B
2014-12-06 Added PWM, FFT, Interrupt, SPI - motors in turned off state
2014-12-06 Updated to pulse motor at frequency and sample at freq
2014-12-07 broken attempt at recieve/transmistter communitoin, dynamic level settting, and frame syncronizatin
2014-12-08 Ttrying real time, fail, commented out
    [main.c]
2014-12-08 Added main with simple uart calls and rumblecation application level driver
2014-12-08 some hold files and a working FFT, vibratory communication with applicatoin layer interface
    [datahold.c, main.c, main_hold.c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]

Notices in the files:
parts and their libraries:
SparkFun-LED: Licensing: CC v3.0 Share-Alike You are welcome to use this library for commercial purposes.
